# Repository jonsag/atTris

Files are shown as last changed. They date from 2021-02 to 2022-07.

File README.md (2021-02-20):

# atTris

## tinyTris

Adapted from work by jaromaz at [https://github.com/jaromaz/ATtiny-Tetris-Gold](https://github.com/jaromaz/ATtiny-Tetris-Gold).  

### Hardware

AS programmer I use [this one](https://github.com/jonsag/ardAVRProgrammer)  

### Software

Connect the avrProgrammer  
Insert the MCU  

Upload the hex  

>$ avrdude -c avrisp -b 19200 -p t85 -P /dev/ttyUSB0 -v -U flash:w:ATtiny-Tetris-Gold.ino.tiny8.hex:i

Set fuses  

>$ avrdude -c avrisp -b 19200 -p t85 -P /dev/ttyUSB0 -v -U lfuse:w:0xf1:m -U hfuse:w:0xdf:m -U efuse:w:0xff:m

## megaTris

My adaption of robsoncuoto's project at [https://github.com/robsoncouto/gm328a_rev_eng](https://github.com/robsoncouto/gm328a_rev_eng).  

## Notes

Reading of ATtiny85, no1, with Tetris  

    Atmega chip detector.
    Written by Nick Gammon.
    Version 1.20
    Compiled on Feb 15 2021 at 16:17:48 with Arduino IDE 10813.
    Attempting to enter ICSP programming mode ...
    Entered programming mode OK.
    Signature = 0x1E 0x93 0x0B 
    Processor = ATtiny85
    Flash memory size = 8192 bytes.
    LFuse = 0x62 
    HFuse = 0xDF 
    EFuse = 0xFF 
    Lock byte = 0xFF 
    Clock calibration = 0x91 
    No bootloader support.

    First 256 bytes of program memory:

    00: 0x4F 0xC2 0x26 0xC5 0x27 0xC9 0x67 0xC2 0x66 0xC2 0x7E 0xCA 0x64 0xC2 0x63 0xC2 
    10: 0x62 0xC2 0x61 0xC2 0x60 0xC2 0x5F 0xC2 0x5E 0xC2 0x5D 0xC2 0x5C 0xC2 0x77 0x77 
    20: 0x00 0x00 0x70 0x77 0x70 0x00 0x70 0x00 0x70 0x77 0x70 0x07 0x70 0x07 0x70 0x07 
    30: 0x00 0xEE 0x70 0x77 0x00 0x0E 0x70 0x07 0xEE 0x00 0x00 0x00 0x00 0x00 0x00 0x00 
    40: 0x00 0x00 0x00 0x00 0x00 0x3F 0x00 0x00 0x00 0x00 0x00 0x00 0x00 0x00 0x00 0x0C 
    50: 0x0C 0x00 0x60 0x30 0x18 0x0C 0x06 0x03 0x01 0x00 0x3E 0x63 0x73 0x7B 0x6F 0x67 
    60: 0x3E 0x00 0x0C 0x0E 0x0C 0x0C 0x0C 0x0C 0x3F 0x00 0x1E 0x33 0x30 0x1C 0x06 0x33 
    70: 0x3F 0x00 0x1E 0x33 0x30 0x1C 0x30 0x33 0x1E 0x00 0x38 0x3C 0x36 0x33 0x7F 0x30 
    80: 0x78 0x00 0x3F 0x03 0x1F 0x30 0x30 0x33 0x1E 0x00 0x1C 0x06 0x03 0x1F 0x33 0x33 
    90: 0x1E 0x00 0x3F 0x33 0x30 0x18 0x0C 0x0C 0x0C 0x00 0x1E 0x33 0x33 0x1E 0x33 0x33 
    A0: 0x1E 0x00 0x1E 0x33 0x33 0x3E 0x30 0x18 0x0E 0x00 0x0C 0x1E 0x33 0x33 0x3F 0x33 
    B0: 0x33 0x00 0x3F 0x66 0x66 0x3E 0x66 0x66 0x3F 0x00 0x3C 0x66 0x03 0x03 0x03 0x66 
    C0: 0x3C 0x00 0x1F 0x36 0x66 0x66 0x66 0x36 0x1F 0x00 0x7F 0x46 0x16 0x1E 0x16 0x46 
    D0: 0x7F 0x00 0x7F 0x46 0x16 0x1E 0x16 0x06 0x0F 0x00 0x3C 0x66 0x03 0x03 0x73 0x66 
    E0: 0x7C 0x00 0x33 0x33 0x33 0x3F 0x33 0x33 0x33 0x00 0x1E 0x0C 0x0C 0x0C 0x0C 0x0C 
    F0: 0x1E 0x00 0x78 0x30 0x30 0x30 0x33 0x33 0x1E 0x00 0x67 0x66 0x36 0x1E 0x36 0x66 

    Programming mode off.

Reading of ATtiny85, no2, with Tetris  

    Atmega chip detector.
    Written by Nick Gammon.
    Version 1.20
    Compiled on Feb 15 2021 at 16:17:48 with Arduino IDE 10813.
    Attempting to enter ICSP programming mode ...
    Entered programming mode OK.
    Signature = 0x1E 0x93 0x0B 
    Processor = ATtiny85
    Flash memory size = 8192 bytes.
    LFuse = 0xF1 
    HFuse = 0xDF 
    EFuse = 0xFF 
    Lock byte = 0xFF 
    Clock calibration = 0x86 
    No bootloader support.

    First 256 bytes of program memory:

    00: 0x4F 0xC2 0x26 0xC5 0x27 0xC9 0x67 0xC2 0x66 0xC2 0x7E 0xCA 0x64 0xC2 0x63 0xC2 
    10: 0x62 0xC2 0x61 0xC2 0x60 0xC2 0x5F 0xC2 0x5E 0xC2 0x5D 0xC2 0x5C 0xC2 0x77 0x77 
    20: 0x00 0x00 0x70 0x77 0x70 0x00 0x70 0x00 0x70 0x77 0x70 0x07 0x70 0x07 0x70 0x07 
    30: 0x00 0xEE 0x70 0x77 0x00 0x0E 0x70 0x07 0xEE 0x00 0x00 0x00 0x00 0x00 0x00 0x00 
    40: 0x00 0x00 0x00 0x00 0x00 0x3F 0x00 0x00 0x00 0x00 0x00 0x00 0x00 0x00 0x00 0x0C 
    50: 0x0C 0x00 0x60 0x30 0x18 0x0C 0x06 0x03 0x01 0x00 0x3E 0x63 0x73 0x7B 0x6F 0x67 
    60: 0x3E 0x00 0x0C 0x0E 0x0C 0x0C 0x0C 0x0C 0x3F 0x00 0x1E 0x33 0x30 0x1C 0x06 0x33 
    70: 0x3F 0x00 0x1E 0x33 0x30 0x1C 0x30 0x33 0x1E 0x00 0x38 0x3C 0x36 0x33 0x7F 0x30 
    80: 0x78 0x00 0x3F 0x03 0x1F 0x30 0x30 0x33 0x1E 0x00 0x1C 0x06 0x03 0x1F 0x33 0x33 
    90: 0x1E 0x00 0x3F 0x33 0x30 0x18 0x0C 0x0C 0x0C 0x00 0x1E 0x33 0x33 0x1E 0x33 0x33 
    A0: 0x1E 0x00 0x1E 0x33 0x33 0x3E 0x30 0x18 0x0E 0x00 0x0C 0x1E 0x33 0x33 0x3F 0x33 
    B0: 0x33 0x00 0x3F 0x66 0x66 0x3E 0x66 0x66 0x3F 0x00 0x3C 0x66 0x03 0x03 0x03 0x66 
    C0: 0x3C 0x00 0x1F 0x36 0x66 0x66 0x66 0x36 0x1F 0x00 0x7F 0x46 0x16 0x1E 0x16 0x46 
    D0: 0x7F 0x00 0x7F 0x46 0x16 0x1E 0x16 0x06 0x0F 0x00 0x3C 0x66 0x03 0x03 0x73 0x66 
    E0: 0x7C 0x00 0x33 0x33 0x33 0x3F 0x33 0x33 0x33 0x00 0x1E 0x0C 0x0C 0x0C 0x0C 0x0C 
    F0: 0x1E 0x00 0x78 0x30 0x30 0x30 0x33 0x33 0x1E 0x00 0x67 0x66 0x36 0x1E 0x36 0x66 

    Programming mode off.

## ATtinyArcade

[webbgoggles, AttinyArcade](https://github.com/webboggles/AttinyArcade)

## More games

[andyhighnumber, Attiny-Arduino-Games](https://github.com/andyhighnumber/Attiny-Arduino-Games)  
>>>>>>> 1e57dbd8131bc683bb3b376d9e93d66b33e94c2e

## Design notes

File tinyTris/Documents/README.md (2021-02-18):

## ATtiny Tetris Gold

This code is designed to run on (very simple and cheap to build) custom hardware and you should find a schematic for the circuit in the folder ATtiny-Tetris-Gold.


   
Designed originally for the Attiny85 and optimised for the *#AttinyArcade* platform. The source code is less than 8KB and the sketch should run happily with less than 300 bytes of RAM. You can find out more about this platform from http://webboggles.com, buy kits to make it (or get instructions / schematics). This sketch includes some code from the #AttinyArcade games on that site, including interrupt code.



This game started life as a port but is now essentially a clone of TinyTetris by Anthony Russell, with some additional features. There remain elements of that original codebase, although the vast majority of what's here has been rewritten from scratch (including the screen, text and number rendering code and much of the game engine) in order to optimise for memory, improve responsiveness and allow new features on the limited hardware (added features include Highscore (saved to EEPROM), optional Ghost (or Shadow) Piece, Interrupt Handling and Hard-Mode functionality).  
   
Anthony's source can be found here: https://github.com/AJRussell/Tiny-Tetris and is highly recommended if you'd like a version of Tetris to run on normal Arduino hardware. It has some lovely graphics by Tobozo (one image from which is now inclded the opening screen here!) and it's also possible that some code by Tobozo has made it into this version. Tobozo's repository can be found here; https://github.com/tobozo and is well worth a look. 
There is an Instructables page relating to this project here: https://www.instructables.com/id/Tetris-Clone-With-OLED-SSD1306I2C-for-Arduino-Nano/ 
        
This sketch is using the screen control and font functions written by Neven Boyanov for the http://tinusaur.wordpress.com/ project
Source code and font files available at: https://bitbucket.org/tinusaur/ssd1306xled - hacked about by Andy Jackson to make them render side-on for this game. All the necessary functions are in this file, there's no need to download any additional libraries to compile this game.

The sleep code in this file is based on this blog post by Matthew Little:
http://www.re-innovation.co.uk/web12/index.php/en/blog-75/306-sleep-modes-on-attiny85

Music, additional sounds and improvements by Jarosław Mazurkiewicz /jaromaz/
http://jm.iq.pl/tetris

### Tetris Multi Button

This interrupt routine relies on having three buttons wired to pin 7 of the Attiny85 - all with a single pull-down resistor (10k) and 
*  One that pulls-up to +Vcc (giving an analog reading of 1023)
*  One that pulls-up via a 1k resistor (analog reading somewhere around 930ish)
*  One that pulls-up via a 2.2 resistor (analog reading around 840)

The key point is that all three buttons provide a voltage that sends the pin to logic-high, thus triggering the interrupt (therefore you could add more buttons, as long as the voltage is always above the threshold that the Attiny85 would class as logic-high). 

In practice, this technique requires a reasonably well made and well insulated board - adding moisture to to board (via damp hands for example) would likely throw the voltages out enough that this technique would become unreliable.

### Before the game starts:
* Hold "DROP" BUTTON - Turns 'ghost' piece on and off
* Hold "DROP" and "ROTATE" together - Turns 'challenge mode' on and off (which fills the screens with random stuff at the start of the game to make it more tricky!)

The code that does not fall under the licenses of sources listed below can be used non-commercially with or without attribution.
This software is supplied without warranty of any kind.

--

Info on programming the Attiny85 chip can be found online, here's an example: https://create.arduino.cc/projecthub/arjun/programming-attiny85-with-arduino-uno-afb829 - don't forget to burn the bootloader (it's a menu option under 'Tools' on the Arduino IDE) the first time you flash the chip and if you need to change to 8Mhz clock.

For more information please visit: https://jm.iq.pl/tetris

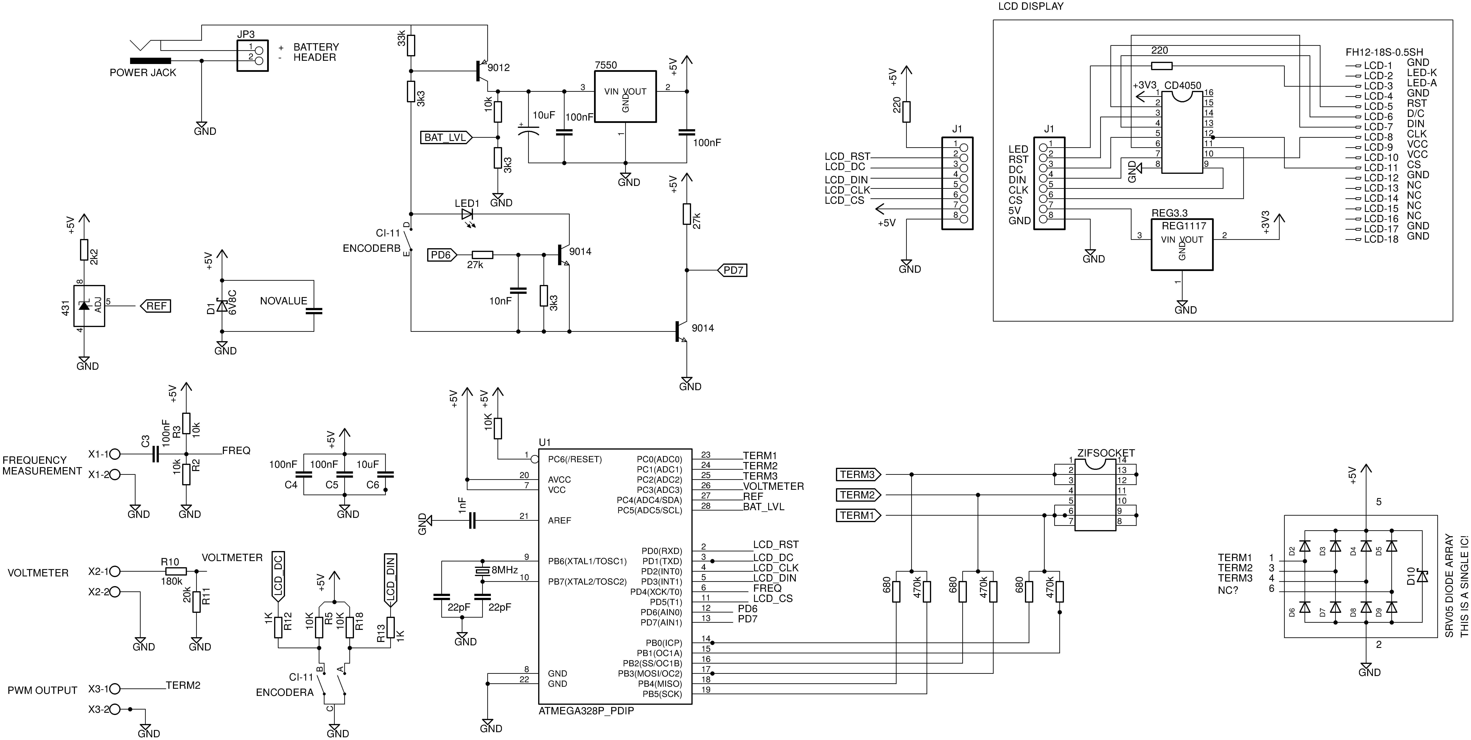
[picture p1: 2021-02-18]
megaTris/Documents/sch2.png

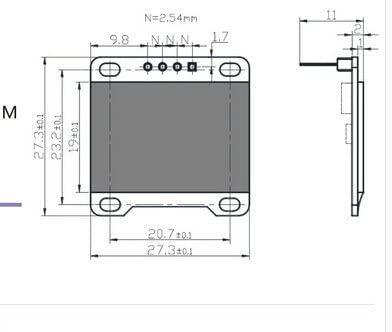
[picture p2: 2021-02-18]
tinyTris/Documents/41CQmQE2IAL._AC_.jpg

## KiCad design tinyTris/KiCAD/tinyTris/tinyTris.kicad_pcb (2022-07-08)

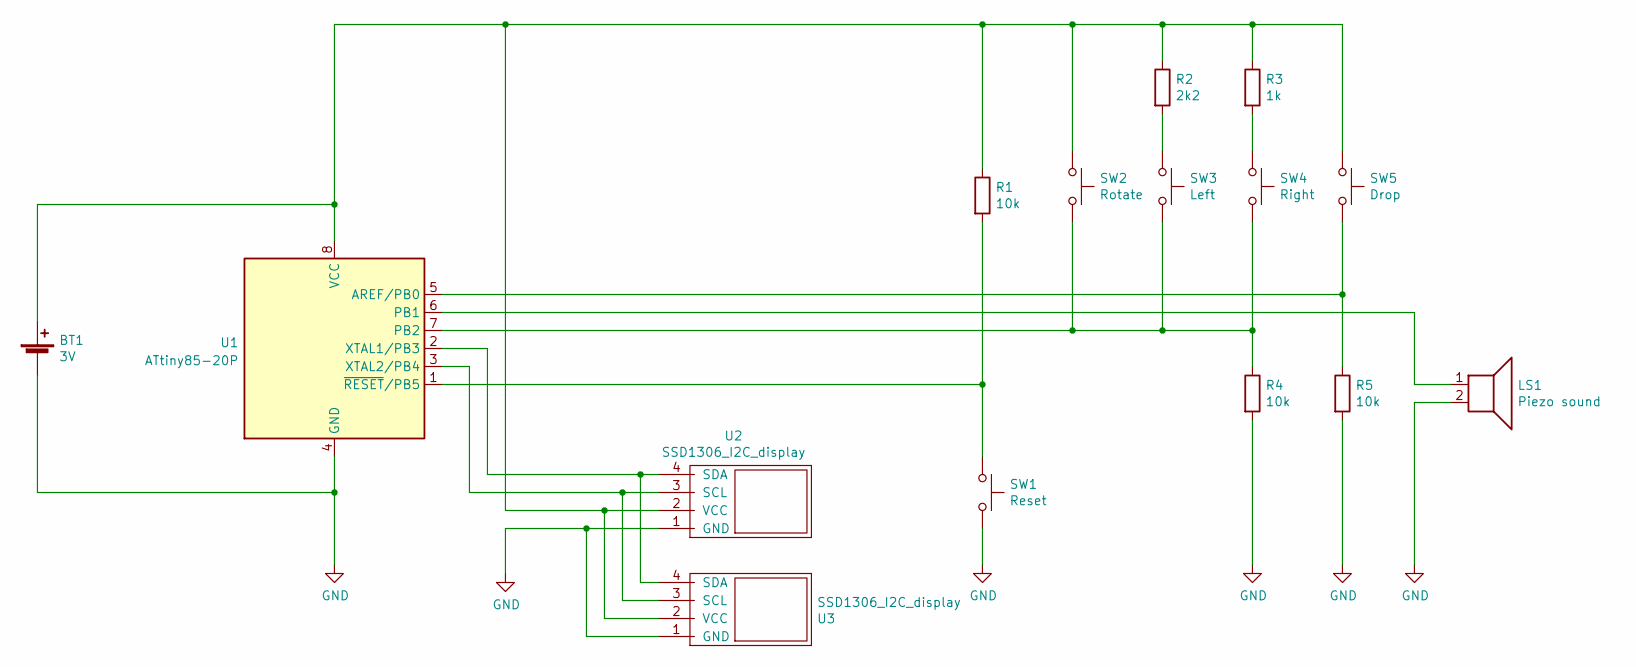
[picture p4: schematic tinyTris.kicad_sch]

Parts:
BT1: 3V; BatteryHolder_Keystone_103_1x20mm
LS1: Piezo sound; Buzzer_TDK_PS1240P02BT_D12.2mm_H6.5mm_large
R1, R4, R5: 10k; R_Axial_DIN0207_L6.3mm_D2.5mm_P10.16mm_Horizontal_larger_pa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
R2: 2k2; R_Axial_DIN0207_L6.3mm_D2.5mm_P10.16mm_Horizontal_larger_pa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
R3: 1k; R_Axial_DIN0207_L6.3mm_D2.5mm_P10.16mm_Horizontal_larger_pa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
SW1: Reset; SW_PUSH_6mm_large
SW2: Rotate; SW_PUSH_6mm_large
SW3: Left; SW_PUSH_6mm_large
SW4: Right; SW_PUSH_6mm_large
SW5: Drop; SW_PUSH_6mm_large
U1: ATtiny85-20P; DIP-8_W7.62mm_Socket_w_dip_packet_LongPads
U2: SSD1306_I2C_display; SSD1306_I2C_0.96_OLED_display_no_display_large
U3: SSD1306_I2C_display; SSD1306_I2C_0.96_OLED_display_large

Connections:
GND: BT1.2 (-), LS1.2, R4.2, R5.2, SW1.2, U1.4 (GND), U2.1 (GND), U3.1 (GND)
unnamed: BT1.1 (+), R1.1, R2.1, R3.1, SW2.1, SW5.1, U1.8 (VCC), U2.2 (VCC), U3.2 (VCC)
unnamed: LS1.1, U1.6 (PB1)
unnamed: R1.2, SW1.1, U1.1 (~RESET/PB5)
unnamed: R2.2, SW3.1
unnamed: R3.2, SW4.1
unnamed: R4.1, SW2.2, SW3.2, SW4.2, U1.7 (PB2)
unnamed: R5.1, SW5.2, U1.5 (AREF/PB0)
unnamed: U1.2 (XTAL1/PB3), U2.4 (SDA), U3.4 (SDA)
unnamed: U1.3 (XTAL2/PB4), U2.3 (SCL), U3.3 (SCL)

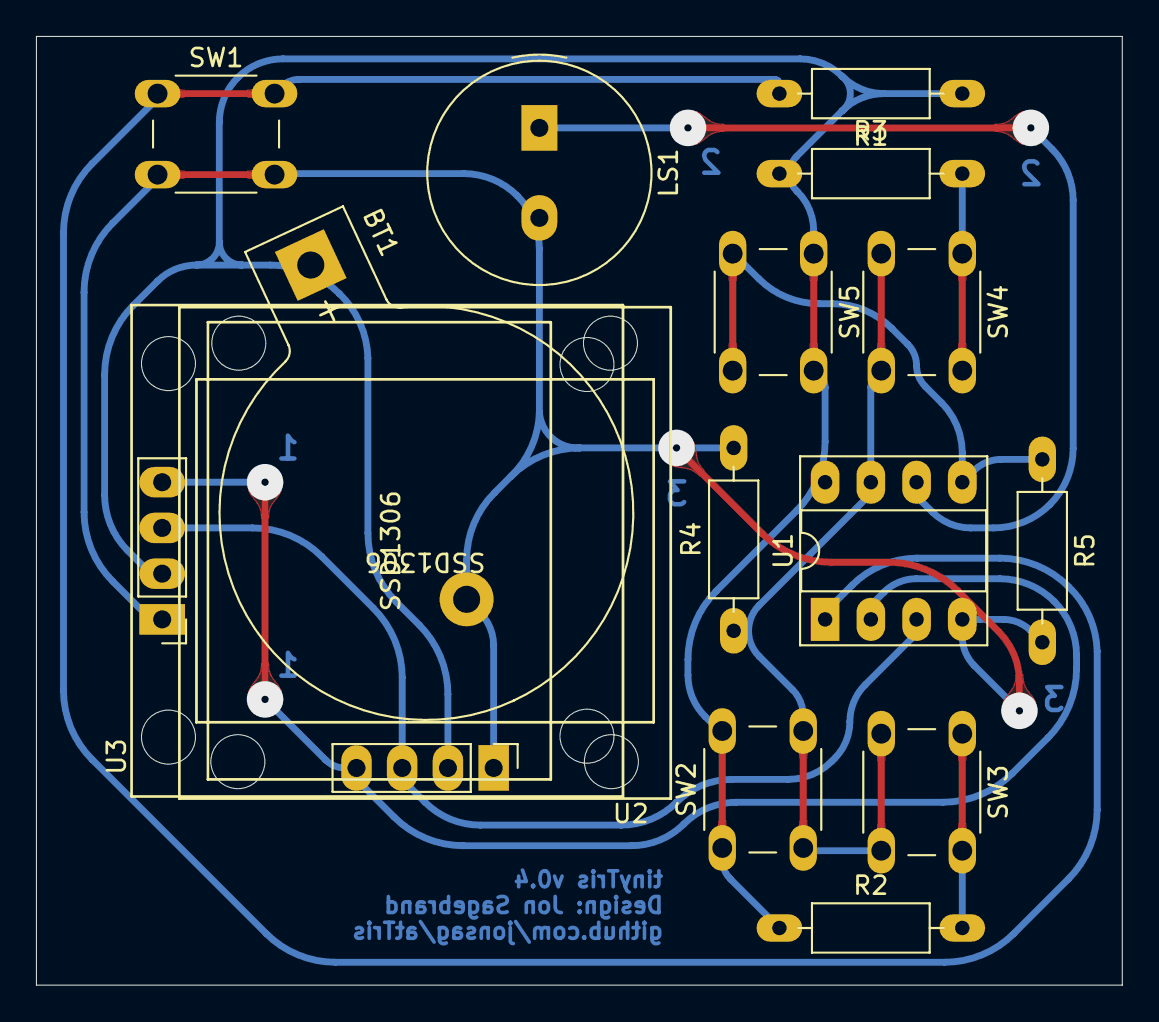
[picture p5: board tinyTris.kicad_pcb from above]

Board: 2 copper layers, 60.3 x 52.7 mm, 15 parts (0 on the bottom side), 10 nets.

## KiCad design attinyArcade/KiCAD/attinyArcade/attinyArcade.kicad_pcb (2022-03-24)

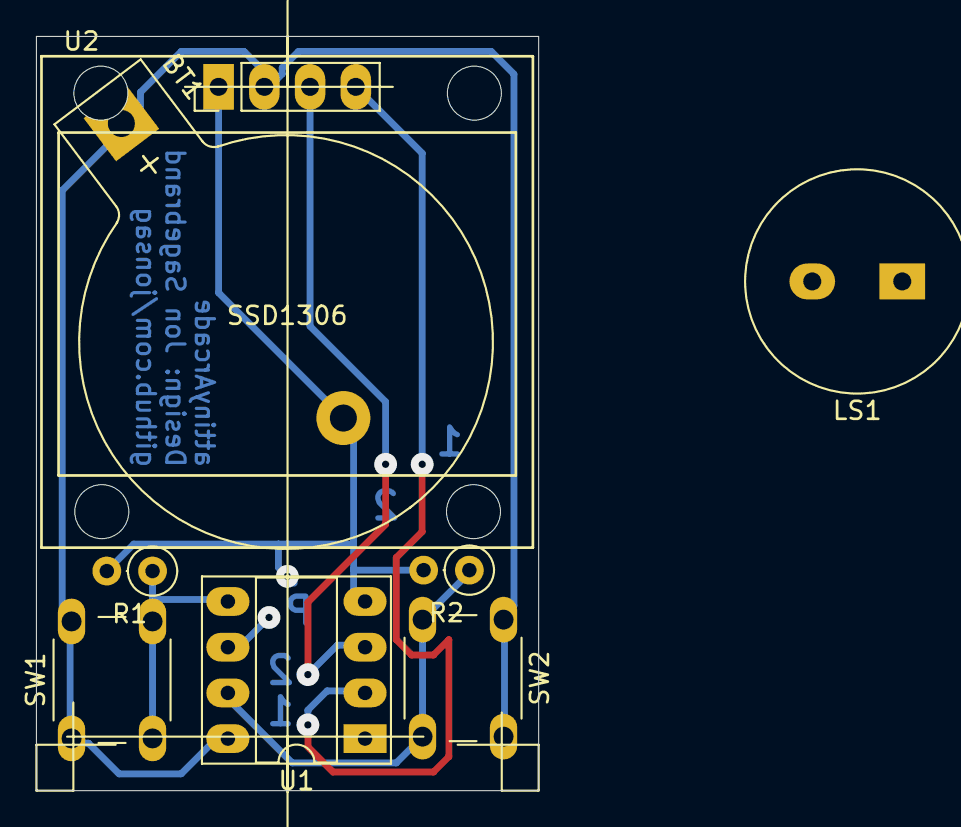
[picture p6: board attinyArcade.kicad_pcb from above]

Board: 2 copper layers, 27.9 x 41.9 mm, 8 parts (0 on the bottom side), 7 nets.

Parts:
BT1: 3V; BatteryHolder_Keystone_103_1x20mm
LS1: Speaker; Buzzer_TDK_PS1240P02BT_D12.2mm_H6.5mm_large
R1, R2: 10k; R_Axial_DIN0207_L6.3mm_D2.5mm_P2.54mm_Vertical_large
SW1, SW2: SW_Push; SW_PUSH_6mm_large
U1: ATtiny85-20P; DIP-8_W7.62mm_Socket_w_dip_packet_LongPads
U2: SSD1306_I2C_display; SSD1306_I2C_0.96_OLED_display_large

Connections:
GND: BT1.2 (-), LS1.2, R1.2, R2.2, U1.4 (GND), U2.1 (GND)
unnamed: BT1.1 (+), SW1.1, SW2.1, U1.8 (VCC), U2.2 (VCC)
unnamed: LS1.1, U1.6 (PB1)
unnamed: R1.1, SW1.2, U1.5 (AREF/PB0)
unnamed: R2.1, SW2.2, U1.7 (PB2)
unnamed: U1.3 (XTAL2/PB4), U2.3 (SCL)
unnamed: U1.2 (XTAL1/PB3), U2.4 (SDA)

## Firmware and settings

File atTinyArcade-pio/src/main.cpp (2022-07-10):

#include <Arduino.h>

#define TetrisGold
//#define Pacman
//#define BatBonanza
//#define Frogger
//#define SpaceAttack
//#define Tetris
//#define TetrisMultiButton
//#define UFOBreakout
//#define UFOStacker
//#define WrenRollercoaster
//#define Morse // not working, circular function call

#ifdef TetrisGold
#include <ATtiny-Tetris-Gold.h>

#else
#ifdef Pacman
#include <Pacman_Attiny_Arcade.h>

#else
#ifdef BatBonanza
#include <BatBonanzaAttinyArcade.h>

#else
#ifdef Frogger
#include <Frogger_Attiny_Arcade.h>

#else
#ifdef SpaceAttack
#include <SpaceAttackAttiny.h>

#else
#ifdef Tetris
#include <Tetris_Attiny_Arcade.h>

#else
#ifdef TetrisMultiButton
#include <Tetris_Multi_Button.h>

#else
#ifdef UFOBreakout
#include <UFO_Breakout_Arduino.h>

#else
#ifdef UFOStacker
#include <UFO_Stacker_Attiny.h>

#else
#ifdef WrenRollercoaster
#include <WrenRollercoasterAttinyArcade.h>

#else
#ifdef Morse
#include <MorseAttinyArcade.h>

#endif
#endif
#endif
#endif
#endif
#endif
#endif
#endif
#endif
#endif
#endif

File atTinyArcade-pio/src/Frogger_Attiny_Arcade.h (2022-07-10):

/*  2015 / 2016 / 2017
 *  Frogger game by Andy Jackson - Twitter @andyhighnumber
 *
 *  Special thanks to @senkunmusahi, who created the artwork bitmaps in the game using https://www.riyas.org/2013/12/online-led-matrix-font-generator-with.html
 *
 *  Inspired by http://webboggles.com/ and includes some code from the #AttinyArcade games on that site
 *  The code that does not fall under the licenses of sources listed below can be used non commercially with attribution.
 *  This software is supplied without warranty of any kind.
 *
 *  Controls:
 *  On the standard AttinyArcade:
 *  LEFT and RIGHT buttons move the frog across
 *  BOTH BUTTONS TOGETHER move the frog forwards
 *
 *  HIGHLY RECOMMENDED:
 *  On custom hardware (see schematic in folder where you found this file) there is an additional button to move frog forward
 *
 *  Also, from standby....
 *  Press and hold left button to turn sound on and off
 *  Press and hold left button with the right button held to reset high score
 *
 *  This sketch is using the screen control and font functions written by Neven Boyanov for the http://tinusaur.wordpress.com/ project
 *  Source code and font files available at: https://bitbucket.org/tinusaur/ssd1306xled
 *  **Note that this highly size-optimized version requires modified library functions (which are in this source code file)
 *  and a modified font header
 *
 *  Sleep code is based on this blog post by Matthew Little:
 *  http://www.re-innovation.co.uk/web12/index.php/en/blog-75/306-sleep-modes-on-attiny85
 */
#include <EEPROM.h>
#include "font6x8AJ2.h"
#include <avr/pgmspace.h>
#include <avr/sleep.h>
#include <avr/interrupt.h> // needed for the additional interrupt

// Uncomment this #define to make the logs smaller (/thinner)
//#define SMALLLOGS

// Make click delay an even number - it gets halved and then used in an integer comparison
#define CLICKDELAY 120

// The baseline speed - higher number is slower
#define MOVEBASE 1000

#define DIGITAL_WRITE_HIGH(PORT) PORTB |= (1 << PORT)
#define DIGITAL_WRITE_LOW(PORT) PORTB &= ~(1 << PORT)

// Routines to set and clear bits (used in the sleep code)
#define cbi(sfr, bit) (_SFR_BYTE(sfr) &= ~_BV(bit))
#define sbi(sfr, bit) (_SFR_BYTE(sfr) |= _BV(bit))

// Defines for OLED output
#define SSD1306XLED_H
#define SSD1306_SCL PORTB4 // SCL, Pin 4 on SSD1306 Board - for webbogles board
#define SSD1306_SDA PORTB3 // SDA, Pin 3 on SSD1306 Board - for webbogles board
#define SSD1306_SA 0x78    // Slave address

// Function prototypes

// Drawing functions - adapted from those at https://bitbucket.org/tinusaur/ssd1306xled
void ssd1306_init(void);
void ssd1306_xfer_start(void);
void ssd1306_xfer_stop(void);
void ssd1306_send_byte(uint8_t byte);
void ssd1306_send_command(uint8_t command);
void ssd1306_send_data_start(void);
void ssd1306_send_data_stop(void);
void ssd1306_setpos(uint8_t x, uint8_t y);
void ssd1306_fillscreen(uint8_t fill_Data);
void ssd1306_char_f6x8(uint8_t x, uint8_t y, const char ch[]);
void ssd1306_draw_bmp(uint8_t x0, uint8_t y0, uint8_t x1, uint8_t y1, uint8_t bitmap[]);

// Custom draw functions - allow for extra functionality like inverse display
void sendBlock(byte, bool);
void sendByte(byte, bool);

// Other generic functions for games (both originated in code from webboggles.com and the sleep code is by Matthew Little - see above)
void beep(int, int);
void system_sleep(void);
void doNumber(int, int, int);

// Game functions
void playFrogger(void);
void levelUp(int);
void moveBlocks(void);
void initScreen(void);
void drawDocks(void);
void drawLives(void);
void displayTitle(void);
void resetDock(byte);
void checkCollision(void);

// Global variables - yes I know all these global vars is a lazy way to code but it makes it easier to prevent stack overflows when you're working with 512 bytes!
// Most of these are initialised in the main game function (playFrogger())
int watchDog;            // Counts drawing cycles so I can shut the game down if there's inactivity - battery saver!
boolean stopAnimate;     // this is set to 1 when a collision is detected
int lives;               // Lives in the game - this can go negative to end the game, which is why it's a signed variable
bool frogDocks[5];       // Tracks which frog docks are full (at the top of the screen)
bool flipFlop;           // Used in routines that flip-flop between two states (left and right)
bool flipFlopShift;      // Same as previous one
byte frogColumn;         // Column location of frog (there are 16 altogether)
byte frogRow;            // Row location of frog (there are 8, but 0 is the frog docks at the top and 7 is the start row)
byte frogLeftLimit;      // Left limit of frog travel on start row (changes as digits in score increases)
byte frogRightLimit;     // Right limit of frog travel on start row (changes as lives decrease as there's then more space)
byte level;              // Level - starts at 1
byte blockShiftL;        // Number of pixels to shift the left-going rows by
byte blockShiftR;        // Number of pixels to shift the right-going rows by
int interimStep;         // Used as timer for incremental movements
int moveDelay;           // How long to wait until the next movement of logs etc - changes as levels increase to make the game go faster
int dockedFrogs;         // How many frogs are in the docks at the top
unsigned long clickBase; // Timer for debounce
boolean clickLock;       // For debounce routine
int score;               // Obvious I hope
int topScore;            // High score
boolean newHigh;         // Is there a new high score?
boolean mute = 0;        // Mute the speaker
byte grid[6][16];        // Grid for items like logs, crocs, cars and lorries
byte frogMode;           // Represents the frog direction
bool moveForward = 0;    // Captures when the 'forward' button is pressed
bool moveLeft = 0;       // Captures when the 'left' button is pressed
bool moveRight = 0;      // Captures when the 'right' button is pressed

// Bitmaps created by @senkunmusahi using https://www.riyas.org/2013/12/online-led-matrix-font-generator-with.html
static const byte bitmaps[15][8] PROGMEM = {
    // Frogs
    {0x83, 0xDC, 0x7A, 0x3F, 0x3F, 0x7A, 0xDC, 0x83},
    {0x99, 0xBD, 0xDB, 0x7E, 0x7E, 0x3C, 0xE7, 0x81},
    {0x81, 0xE7, 0x3C, 0x7E, 0x7E, 0xDB, 0xBD, 0x99},
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

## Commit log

2022-03-24 tinyTris Kicad6
    [tinyTris.kicad_pcb, tinyTris.kicad_sch, tinyTris.sch]
2022-07-08 new schematics
    [tinyTris.kicad_pcb, tinyTris.kicad_sch]
